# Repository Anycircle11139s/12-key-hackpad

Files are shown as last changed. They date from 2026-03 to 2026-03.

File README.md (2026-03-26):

# 16 key hackpad with OLED
This is my 16-key hackpad which has 16 keys and an oled screen. I made it so I can use all 16 keys for different shortcuts and stuff, because I'm not bothered to move  my hand an extra 2mm every 10 hours. This is my CAD, I looked at the kicad pcb and measured with the ruler to find the measurements to place the oled and keys in the correct places. The CADing was pretty easy overall.

Screenshot 2026-03-22 at 6 55 59 pm
Screenshot 2026-03-22 at 6 55 48 pm
Screenshot 2026-03-22 at 6 55 44 pm
Screenshot 2026-03-22 at 6 55 26 pm

This is my PCB design, after creating the schematic, I imported it into the pcb editor and arranged the parts, which was pretty easy. But then I had to do the wiring, I started from the top and went down but it was extremely annoying and mind-numbing, finally, after a while, I managed to complete it. I have so many vias... :( I also had a bit of trouble fitting it into the 100 by 100 millimetre pcb size limit, but I barely made it.

Screenshot 2026-03-22 at 7 51 20 pm

This is my schematic, I started by creating the 4 by 4 matrix for the buttons, then I connected it to the rp2040. Next, I added the oled and connected that to the rp2040. The hardest part was creating the matrix which took me a while and a lot of reddit searching, but after that, it got a lot simpler.

Screenshot 2026-03-26 at 1 18 49 pm

BOM: 16x Cherry MX Switches 1x XIAO RP2040 16x Blank DSA Keycaps 4x M3x16 Bolt 4x M3 Heatset 1x 0.91 Oled display 8x SK6812 Mini RGB LEDs

| Name | Quantity | Cost Per Item (USD) | Total (USD) | Purpose | Distributor | Link |
|---|---|---|---|---|---|---|
| PCB fabrication and shipping | 1 | $3.50 | $3.50 | pcb for my hackpad | JLCPCB | [Link]((https://trade.jlcpcb.com/checkout/payMethod/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)) |
| Ali Express shipping and fees | 1 | $4.73 | $4.73 | Shipping | Ali Express | [Link] |
| M3x5mx4mm heatset inserts | 1 | $4.09 | $4.09 | secure threading for the M3 screw | Ali Express | [Link](https://www.aliexpress.us/item/2255800046543591.html) |
| M3x16mm screws | 1 | $1.05 | $1.05 | Secures top and bottom parts of the cases together | Ali Express | [Link](https://www.aliexpress.us/item/3256805692722422.html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) |
| 1u Key caps | 1 | $3.79 | $3.79 | The covering for the keys | Ali Express | [Link](https://www.aliexpress.com/item/1005008678389468.html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) |
| 5-pin PCB-mount switch | 30 pack (No 20 or 16 option) | $8.00 | $8.00 | The keyboard keys | Ali Express | [Link](https://www.aliexpress.us/item/3256806239135691.html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) |
| 5V SK6812MINI-E rgb leds | 10 | $0.283 | $2.83 | Shows colours to indicate signals | Ali Express | [Link](https://www.aliexpress.us/item/3256805154503907.html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) |
| 0.91 inch SSD1306 I2C 128x32 OLED display | 1 | $2.85 | $2.85 | Displays information and animations | Ali Express | [Link](https://www.aliexpress.com/item/1005006823025817.html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!) |
| Seed Xiao - RP2040 | 1 | $4.68 | $4.68 | Microcontroller - the power source and control | Ali Express | [Link](https://www.aliexpress.com/item/1005008652799938.html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) |
| Diodes | 1 | $2.74 | $2.74 | Diodes, so no ghost| Ali Express | [Link](https://www.aliexpress.com/item/1005007606166130.html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) |
| Case shipping and printing | 1 | $6.50 | $6.50 | Case for hackpad | Printing legion | [Link] |

**Total cost: $38.26**

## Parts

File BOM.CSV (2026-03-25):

Name | "Quantity" | Cost Per Item (USD) | Total (USD) | Purpose | Distributor | Link
PCB fabrication and shipping | 1 | $3.50 | $3.50 | pcb for my hackpad | JLCPCB | No Link
Case printing and shipping | 1 | $6.50 | $6.50 | case for my hackpad | Printing Legion | No Link
Ali Express shipping and fees | 1 | $4.73 | $4.73 | Shipping | Ali Express | No Link
M3x5mx4mm heatset inserts | 1 | $4.09 | $4.09 | secure threading for the M3 screw | Ali Express | https://www.aliexpress.us/item/2255800046543591.html
M3x16mm screws | 1 | $1.05 | $1.05 | Secures top and bottom parts of the cases together | Ali Express | https://www.aliexpress.us/item/3256805692722422.html
1u Key caps | 1 | $3.79 | $3.79 | The covering for the keys | Ali Express | https://www.aliexpress.com/item/1005008678389468.html?curPageLogUid=USF9TxF5Xjpt
5-pin PCB-mount switch | 30 pack (No 20 or 16 option) | $8.00 | $8.00 | The keyboard keys | Ali Express | https://www.aliexpress.us/item/3256806239135691.html?curPageLogUid=wFaqavLZ7pag
5V SK6812MINI-E rgb leds | 10 | $0.283 | $2.83 | Shows colours to indicate signals | Ali Express | https://www.aliexpress.us/item/3256805154503907.html?mp=1
0.91 inch SSD1306 I2C 128x32 OLED display | 1 | $2.85 | $2.85 | Displays information and animations | Ali Express | https://www.aliexpress.com/item/1005006823025817.html?mp=1
Seed Xiao - RP2040 | 1 | $4.68 | $4.68 | Microcontroller - the power source and control | Ali Express | https://www.aliexpress.com/item/1005008652799938.html?curPageLogUid=1OKs76xZs5r6
Diodes | 1 | $2.74 | $2.74 | Diodes, so no ghost | Ali Express | https://www.aliexpress.com/item/1005007606166130.html?curPageLogUid=ELi0JhSGGJBV
Total Cost | $38.26

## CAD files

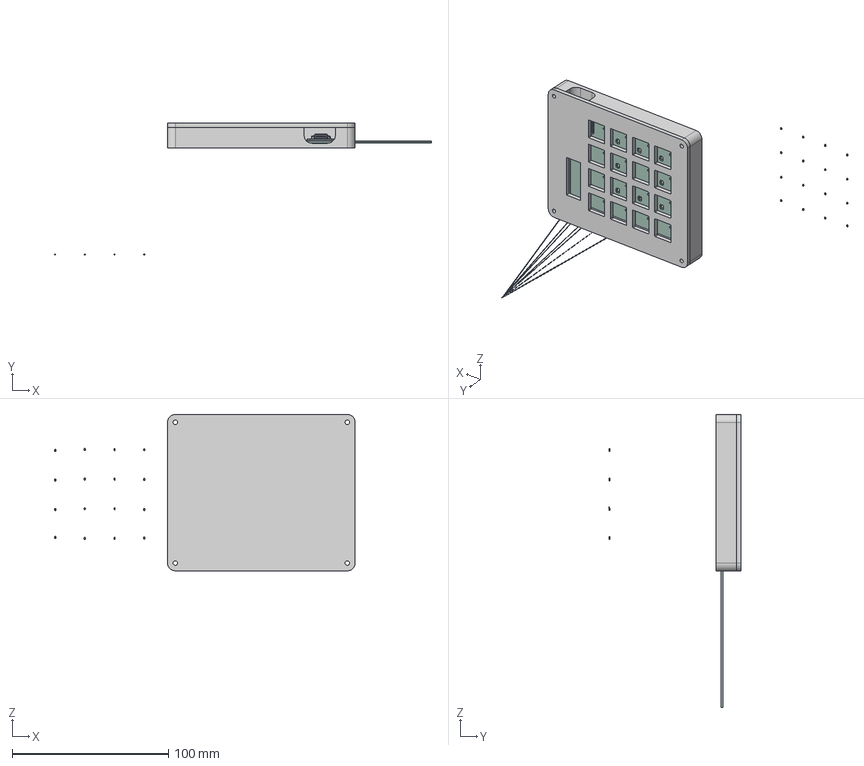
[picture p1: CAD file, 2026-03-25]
CAD/Final assemby 12 key hackpad actual.step
241.1 x 84.6 x 187.4 mm
D_SOD-523 x 16
Krish hackpad_PCB
type-c v2
smd_button v3
DOUT
DIN
VSS
VDD
smd_button v3(Mirror)
krish hackpad

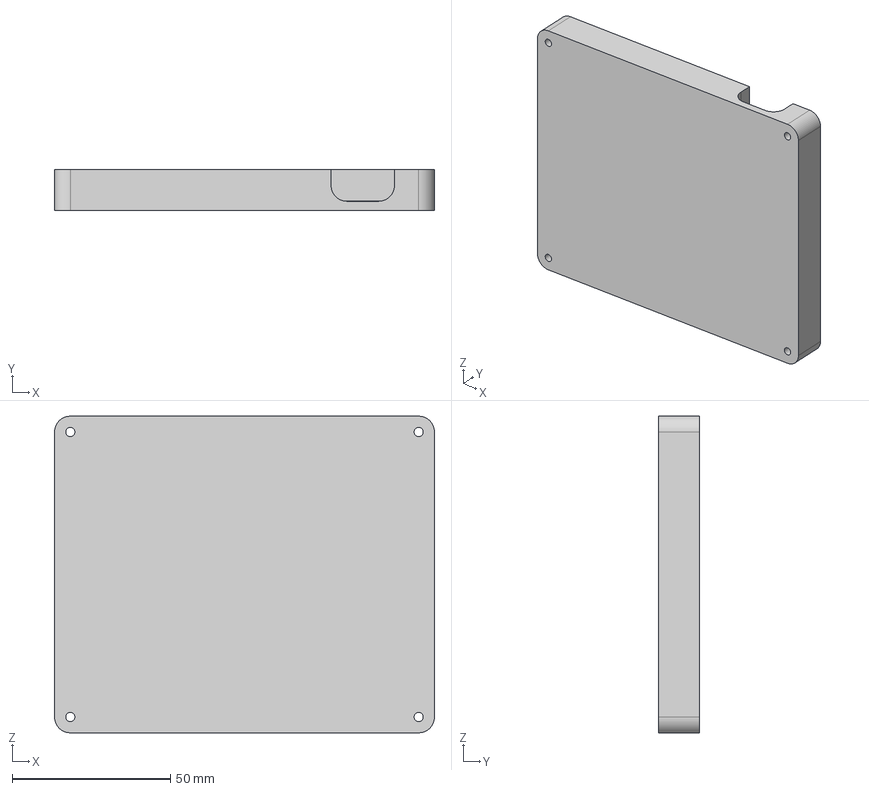
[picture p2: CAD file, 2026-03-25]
Production/12keybottom.step
120.0 x 13.0 x 100.0 mm

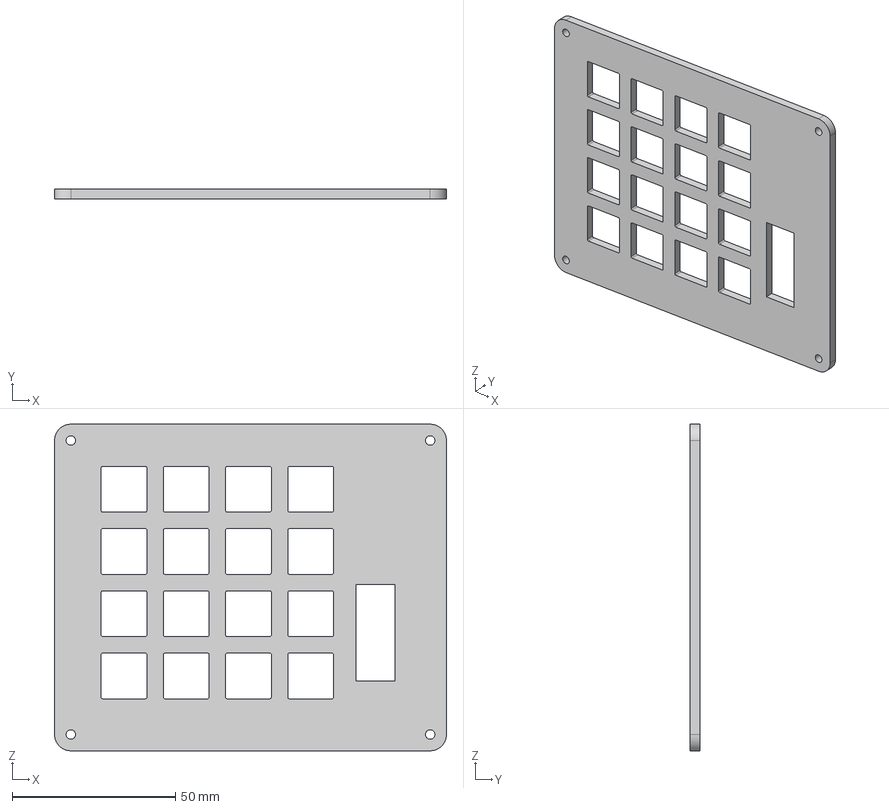
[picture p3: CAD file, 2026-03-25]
Production/12keytop.step
120.0 x 3.00 x 100.0 mm

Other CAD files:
CAD/Final assemby 12 key hackpad actual.f3d

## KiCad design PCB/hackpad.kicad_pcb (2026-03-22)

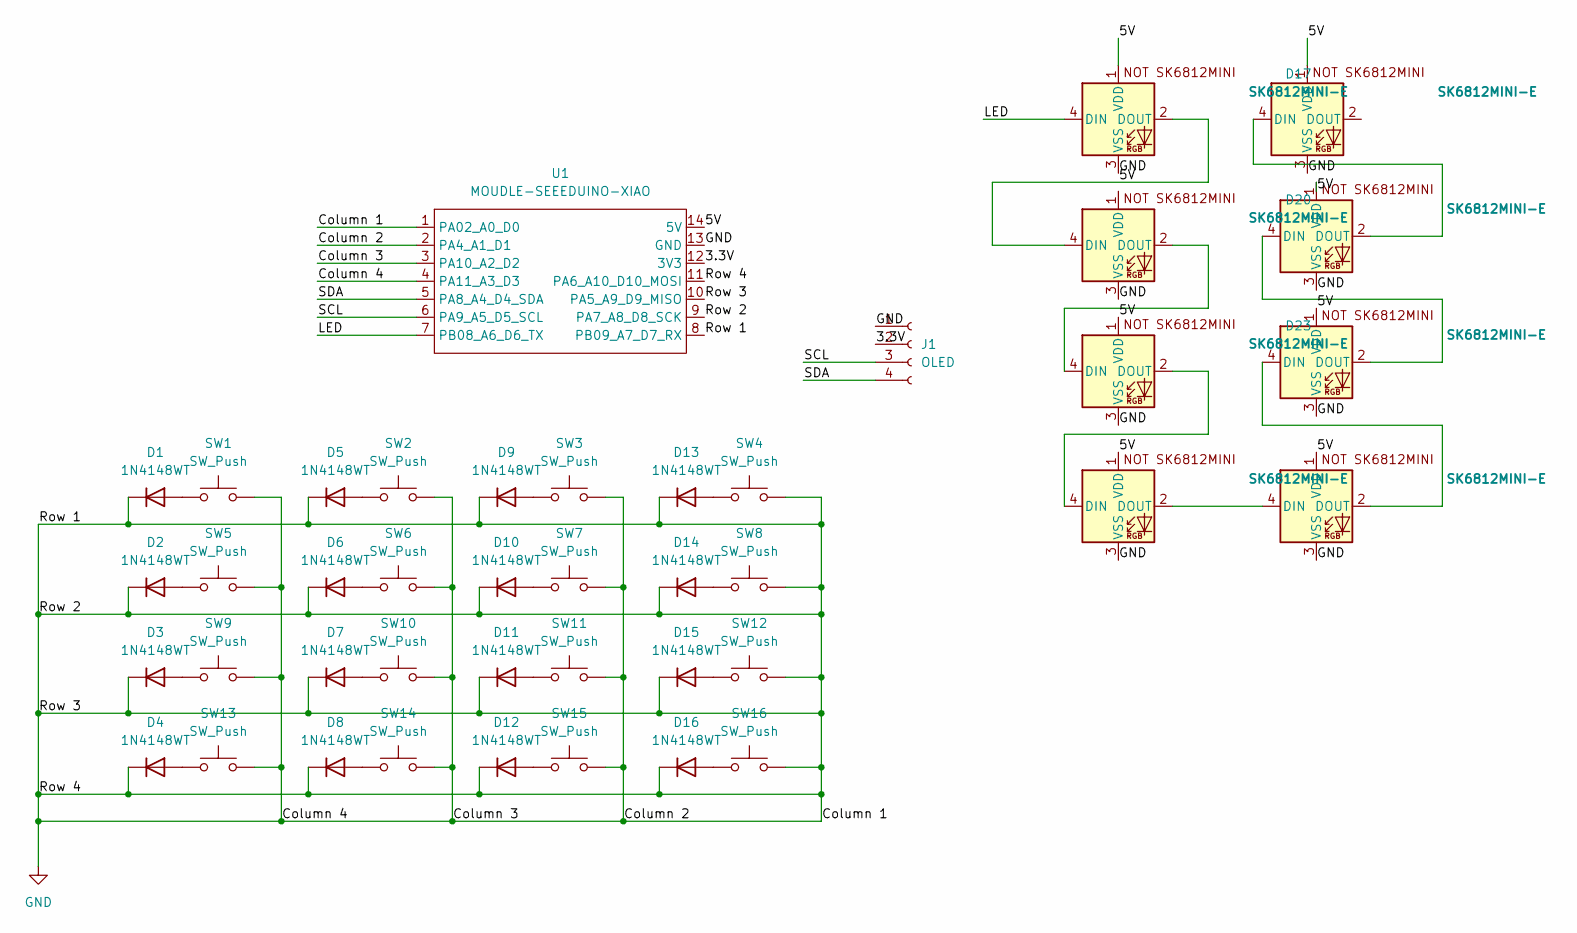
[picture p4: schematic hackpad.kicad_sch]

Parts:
D1, D2, D3, D4, D5, D6, D7, D8, D9, D10, D11, D12, D13, D14, D15, D16: 1N4148WT; D_SOD-523
D17, D18, D19, D20, D21, D22, D23, D24: SK6812MINI-E; SK6812MINI-E_fixed
J1: OLED
SW1, SW2, SW3, SW4, SW5, SW6, SW7, SW8, SW9, SW10, SW11, SW12, SW13, SW14, SW15, SW16: SW_Push; SW_Cherry_MX_1.00u_PCB
U1: MOUDLE-SEEEDUINO-XIAO; XIAO-Generic-Hybrid-14P-2.54-21X17.8MM

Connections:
/3.3V: J1.2, U1.12 (3V3)
/5V: D17.1 (VDD), D17.2 (DOUT), D18.1 (VDD), D19.1 (VDD), D20.4 (DIN), D21.1 (VDD), D22.1 (VDD), D23.1 (VDD), D24.1 (VDD), U1.14 (5V)
/LED: D17.4 (DIN), U1.7 (PB08_A6_D6_TX)
/SCL: J1.3, U1.6 (PA9_A5_D5_SCL)
/SDA: J1.4, U1.5 (PA8_A4_D4_SDA)
GND: D1.1 (K), D2.1 (K), D3.1 (K), D4.1 (K), D5.1 (K), D6.1 (K), D7.1 (K), D8.1 (K), D9.1 (K), D10.1 (K), D11.1 (K), D12.1 (K), D13.1 (K), D14.1 (K), D15.1 (K), D16.1 (K), D17.3 (VSS), D18.3 (VSS), D19.3 (VSS), D20.3 (VSS), D21.3 (VSS), D22.3 (VSS), D23.3 (VSS), D24.3 (VSS), J1.1, SW1.2, SW2.2, SW3.2, SW4.2, SW5.2, SW6.2, SW7.2, SW8.2, SW9.2, SW10.2, SW11.2, SW12.2, SW13.2, SW14.2, SW15.2, SW16.2, U1.1 (PA02_A0_D0), U1.2 (PA4_A1_D1), U1.3 (PA10_A2_D2), U1.4 (PA11_A3_D3), U1.8 (PB09_A7_D7_RX), U1.9 (PA7_A8_D8_SCK), U1.10 (PA5_A9_D9_MISO), U1.11 (PA6_A10_D10_MOSI), U1.13 (GND)
unnamed: D1.2 (A), SW1.1
unnamed: D2.2 (A), SW5.1
unnamed: D3.2 (A), SW9.1
unnamed: D4.2 (A), SW13.1
unnamed: D5.2 (A), SW2.1
unnamed: D6.2 (A), SW6.1
unnamed: D7.2 (A), SW10.1
unnamed: D8.2 (A), SW14.1
unnamed: D9.2 (A), SW3.1
unnamed: D10.2 (A), SW7.1
unnamed: D11.2 (A), SW11.1
unnamed: D12.2 (A), SW15.1
unnamed: D13.2 (A), SW4.1
unnamed: D14.2 (A), SW8.1
unnamed: D15.2 (A), SW12.1
unnamed: D16.2 (A), SW16.1
unnamed: D18.4 (DIN), D23.2 (DOUT)
unnamed: D18.2 (DOUT), D22.4 (DIN)
unnamed: D19.4 (DIN), D21.2 (DOUT)
unnamed: D20.2 (DOUT), D23.4 (DIN)
unnamed: D21.4 (DIN), D24.2 (DOUT)
unnamed: D22.2 (DOUT), D24.4 (DIN)

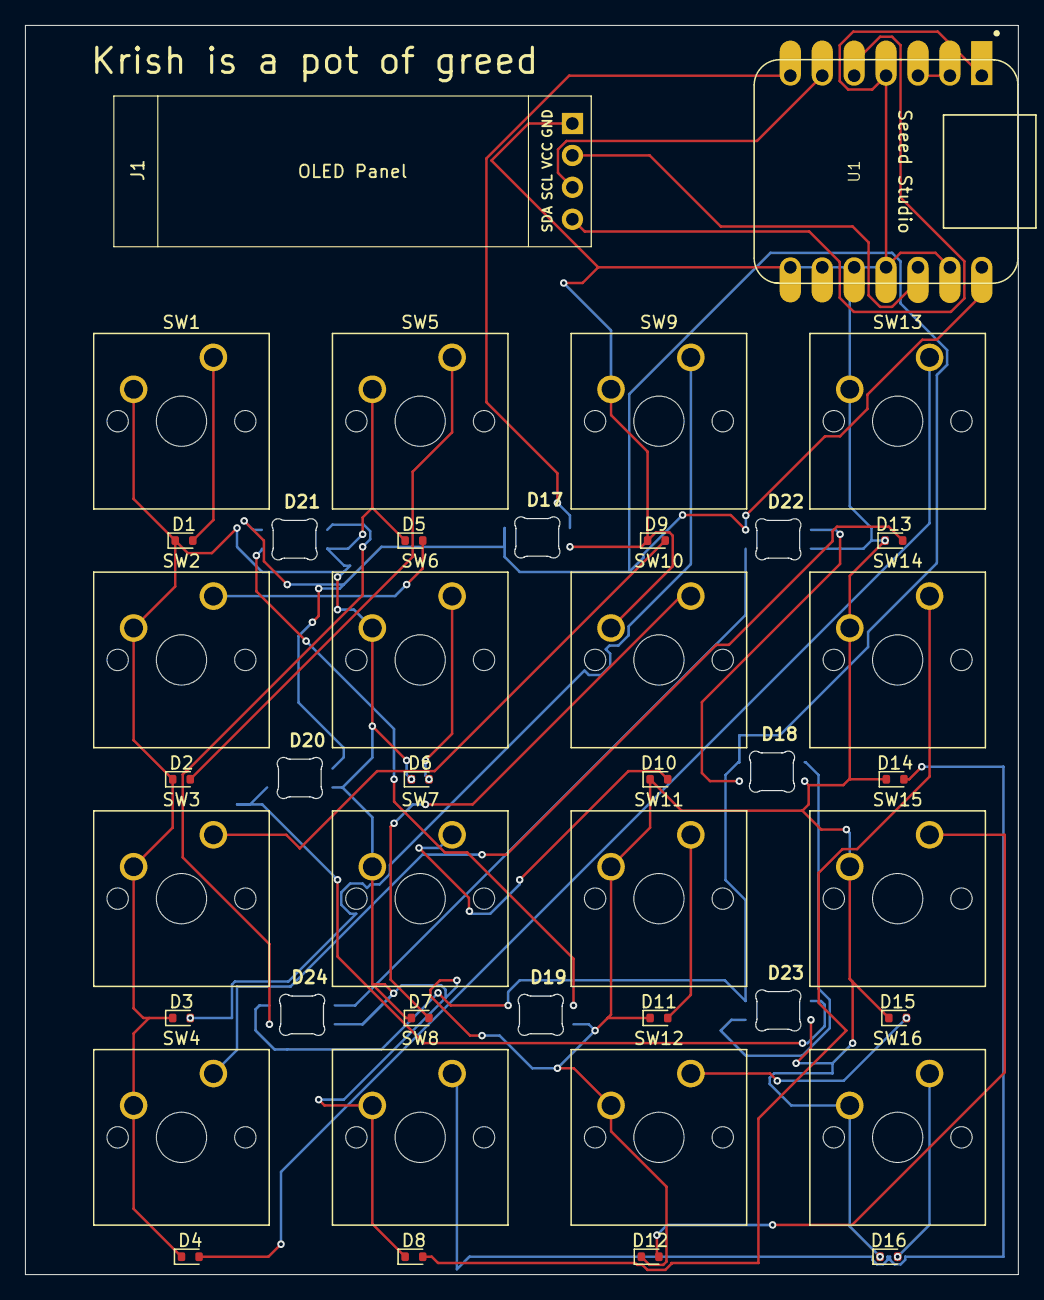
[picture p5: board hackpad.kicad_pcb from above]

Board: 2 copper layers, 79.0 x 99.4 mm, 42 parts (0 on the bottom side), 28 nets.

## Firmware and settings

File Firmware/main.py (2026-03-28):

import board
import busio
from kmk.kmk_keyboard import KMKKeyboard
from kmk.keys import KC
from kmk.scanners import DiodeOrientation
from kmk.extensions.peg_oled_display import Oled, OledDisplayMode, OledReactionType, OledData

keyboard = KMKKeyboard()

# HARDWARE SETUP
keyboard.col_pins = (board.D0, board.D1, board.D2, board.D3)
keyboard.row_pins = (board.D6, board.D7, board.D8, board.D9)
keyboard.diode_orientation = DiodeOrientation.COL2ROW

# OLED SETUP
i2c_bus = busio.I2C(board.SCL, board.SDA)

oled_ext = Oled(
    OledData(
        corner_one={0: OledReactionType.STATIC, 1: ["Hack Club"]}
    ),
    toDisplay=OledDisplayMode.TXT,
    flip=False,
    i2c=i2c_bus
)
keyboard.extensions.append(oled_ext)

#  16-KEY MATRIX LAYOUT
keyboard.keymap = [
    [
        KC.N7,   KC.N8,   KC.N9,   KC.MUTE,
        KC.N4,   KC.N5,   KC.N6,   KC.VOLU,
        KC.N1,   KC.N2,   KC.N3,   KC.VOLD,
        KC.ESC,  KC.N0,   KC.ENTER, KC.MPLY
    ]
]

if __name__ == '__main__':
    keyboard.go()

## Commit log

2026-03-22 Rename Krish hackpad.kicad_sch to Firmware/hackpad.kicad_sch
    [hackpad.kicad_sch]
2026-03-22 Rename Krish hackpad.kicad_pcb to Firmware/hackpad.kicad_pcb
    [hackpad.kicad_pcb]
2026-03-22 Rename Krish hackpad.kicad_prl to Firmware/hackpad.kicad_prl
2026-03-22 Rename Krish hackpad.kicad_pro to Firmware/hackpad.kicad_pro
2026-03-22 Rename Final assemby 12 key hackpad.f3z to CAD/Final assemby 12 key hackpad.f3z
    [Final assemby 12 key hackpad.f3z]
2026-03-22 Rename Final assemby 12 key hackpad.step to CAD/Final assemby 12 key hackpad.step
    [Final assemby 12 key hackpad.step]
2026-03-22 Rename Krish hackpad.kicad_pcb to hackpad.kicad_pcb
    [hackpad.kicad_pcb]
2026-03-22 Rename Krish hackpad.kicad_sch to hackpad.kicad_sch
    [hackpad.kicad_sch]
2026-03-22 Rename Krish hackpad.kicad_pro to hackpad.kicad_pro
2026-03-22 Rename Krish hackpad.kicad_prl to hackpad.kicad_prl
2026-03-22 Modify BOM.CSV with updated product links
    Updated entries for PCB fabrication and Ali Express shipping with new links.
    [BOM.CSV]
2026-03-22 Update BOM.CSV with new items and links
    Updated BOM.CSV to add new items and links, and modify existing entries.
    [BOM.CSV]
2026-03-22 Update BOM.CSV with new components and links
    Removed items from BOM.CSV and added new entries.
    [BOM.CSV]
2026-03-22 Update BOM.CSV with new component entries
    [BOM.CSV]
2026-03-22 Update BOM.CSV with total cost calculation
    [BOM.CSV]
2026-03-25 Update cost for case printing and shipping
    [BOM.CSV]
